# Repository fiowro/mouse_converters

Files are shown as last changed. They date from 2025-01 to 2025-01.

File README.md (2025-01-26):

# mouse_converters

This repo keeps sources (Arduino sketches, STL files for 3D printed parts, pinouts, etc.) for USB mouse converters we created to try out various mice and trackballs while studying the history of cursor control devices. 
Results of the research have their own repo, [github.com/fiowro/mouses](https://github.com/fiowro/mouses) and a dedicated website, [mouses.info](https://mouses.info).

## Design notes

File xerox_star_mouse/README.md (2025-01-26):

# USB Xerox Star mouse converter

This prject allows you to plug Xerox Star two- and three-button mice into USB and use them with any modern computer.

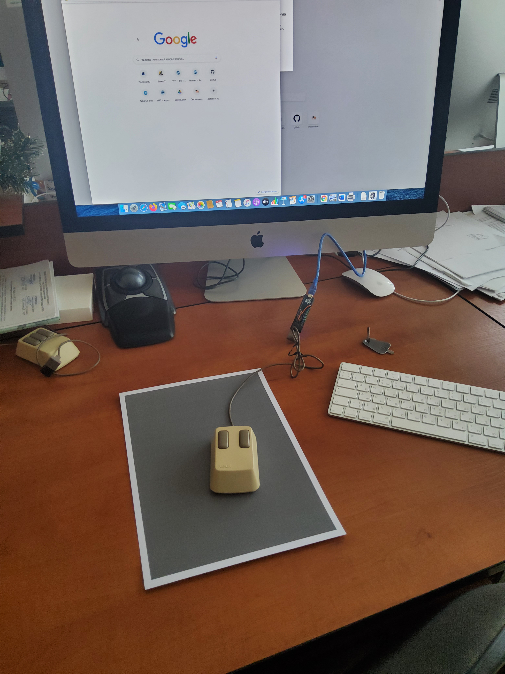
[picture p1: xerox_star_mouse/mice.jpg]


The converter is based on Arduino Pro Micro and uses a sophisticated 3D printed case.

## Mouse jack

Except early versions, these mice have a really esoteric jack:

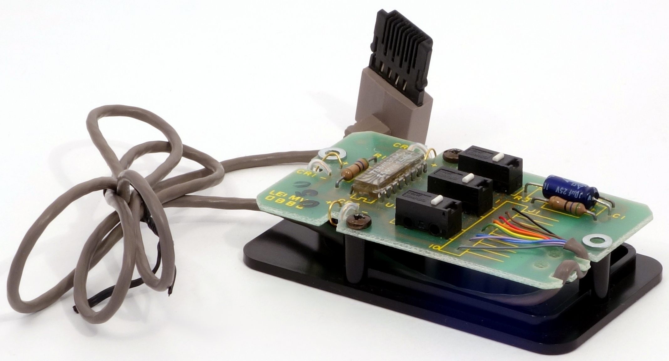
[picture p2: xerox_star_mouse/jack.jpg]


The socket was mounted in the Xerox keyboard and looks like this:

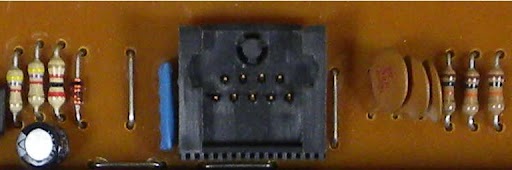
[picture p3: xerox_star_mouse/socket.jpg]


We couldn't find any spare parts, and had to 3D print it as a part of the converter case.
 
The case consists of two parts, one inserted into another (as a drawer).

## Pinout

Xerox Mice are plain quadrature (parallel) cursor movers. It means that coordinates are encoded as Xa, Xb, Ya, Yb, also there are 2 or 3 lines for buttons, power, and ground.
Mouse uses colored wires. 

The pinout of the mouse was figured out experimentally tracking the wires and printed board.

|No.| color | No. | Connected to | Meaning |
|---|---|-----|---|---|
| 1 | red |  3  | U1 ( 7 / 10) | YB |
| 2 | brown |  2  | U1 ( 8 /  9) | YA |
| 3 | yellow|  5  | U1 ( 5 / 12) | XB |
| 4 | orange|  4  | U1 ( 6 / 11) | XA |
| 5 | gray  | 10  | +5V U1 ( 1 / 16) |VDD (+5V)|
| 6 | violet|  8  | GND U1 ( 9 /  8) | GND |
| 7 | black |  1  | S1, U1 (12 /  5) | BD A |
| 8 | blue  |  7  | S2, U1 (15 /  2) | RD B |
| 9 | green |  6  | S3, U1 (14 /  3) | YD A |
| | NC |  9  | GND | |

## Assembly

3D Print the case:

* [ArdMouse4-Body.stl](ArdMouse4-Body.stl) (main part)
* [ArdMouse4-Body001.stl](ArdMouse4-Body001.stl) (cover)

You will need inserting pins into the holes of the *main part* to "assembly" jack.
For example, you can cut off pins from Arduino and use them.

See the [sketch](XeroxDuino.ino) for Arduino pins where to connect the wires (or use your own variant and modify the sketch).

BTW, the sketch is heavily based on the [AmigaInputToUSB](https://github.com/BleuLlama/AmigaInputToUSB) project. 

## Usage

We [recreated the mouse pad](Xerox_mousepad_A4.png) from scratch. You can print it on paper (Xerox did the same) and use.

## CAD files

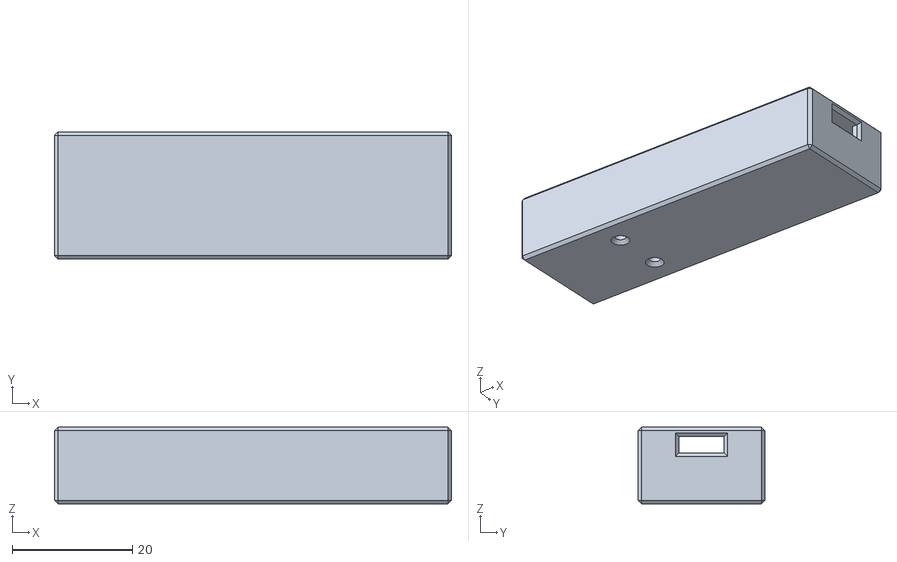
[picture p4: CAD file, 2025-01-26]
xerox_star_mouse/ArdMouse4-Body001.stl
66.1 x 21.2 x 12.8

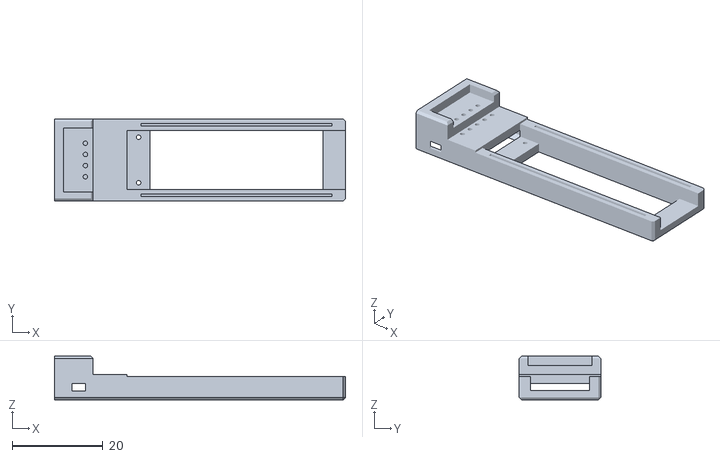
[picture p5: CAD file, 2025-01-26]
xerox_star_mouse/ArdMouse4-Body.stl
64.0 x 18.0 x 9.60

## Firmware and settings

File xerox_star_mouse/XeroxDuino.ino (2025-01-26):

#include <Mouse.h>

// Mouse
#define mousePinYa SCK
#define mousePinXa 7
#define mousePinYb MISO
#define mousePinXb MOSI

// Mouse buttons (common for both)
#define buttonPinL (5)  /* left button (A1) */
#define buttonPinR (6)  /* right button (A3) */
#define buttonPinM (4)  /* middle button (A2) */

// on-board LED pin
// #define kLED (17)

// ----------------------------------------

// setup - initialize the hardware
void setup() {
  pinMode( LED_BUILTIN, OUTPUT );
  
  // set the mouse and button inputs
  pinMode( mousePinYa, INPUT );
  pinMode( mousePinXa, INPUT );
  pinMode( mousePinYb, INPUT );
  pinMode( mousePinXb, INPUT );
  pinMode( buttonPinM, INPUT );
  pinMode( buttonPinL, INPUT );
  pinMode( buttonPinR, INPUT );
  
 // Serial.begin( 9600 );
  Mouse.begin(); // for USB HID Mouse support
  initGrayMouse(); 

}

// mouse movement history, used for acceleration
char history_x[128];
char history_y[128];
int historyPos=0; // current write position in the history

// initialize for gray code mouse 
void initGrayMouse( void )
{
  // clear the history
  for( int h=0 ; h<128 ; h++ ) {
    history_x[h] = history_y[h] = 0;
  }
}

// provide a total of all X history values (for acceleration)
int total_x( void )
{
  int ret = 0;
  for( int i=0 ; i < 128 ; i++ )
  {
    ret += history_x[i];
  }
  return ret;
}

// provide a total of all Y history values (for acceleration)
int total_y( void )
{
  int ret = 0;
  for( int i=0 ; i < 128 ; i++ )
  {
    ret += history_y[i];
  }
  return ret;
}


// compare A and B to determine the delta
  // +  00 -> 01 -> 11 -> 10 -> 00 
  // -  00 -> 10 -> 11 -> 01 -> 00
int grayCompare( int a, int b )
{
  a = a & 0x03;
  b = b & 0x03;
  if( a == b ) return 0;
  switch( a ) {
    case( 0x00 ):
      if( b == 0x01) return +1;
      if( b == 0x10) return -1;
      break;
    case( 0x01 ):
      if( b == 0x11) return +1;
      if( b == 0x00) return -1;
      break;
    case( 0x11 ):
      if( b == 0x10) return +1;
      if( b == 0x01) return -1;
      break;
    case( 0x10 ):
      if( b == 0x00) return +1;
      if( b == 0x11) return -1;
      break;
  }
  return 0;
}

// the main gray mouse loop
void loopGrayMouse()
{
  bool changed = false; // did something change?
  
  // these are static so they persist between calls
  static int x_accum = 0; // accumulated X
  static int y_accum = 0; // accumulated Y

  static int last_hq = 0; // last h quadrature
  static int last_vq = 0; // last v quadrature
  
  // read in the quad/gray code
  int hq = 0;
  int vq = 0;
  
  hq = (digitalRead( mousePinXa ) << 1) | digitalRead( mousePinXb );
  vq = (digitalRead( mousePinYa ) << 1) | digitalRead( mousePinYb );
    
  // check horizontal delta
  if( hq != last_hq ) {
    x_accum += grayCompare( hq, last_hq );
    changed = true;
  }
  last_hq = hq;
  
  // and vertical delta
  if( vq != last_vq ) {
    y_accum += grayCompare( vq, last_vq );
    changed = true;
  }
  last_vq = vq;
    
  // generate the acceleration info from gray tick
  historyPos++;
  history_x[ (historyPos & 0x7f) ] = x_accum;
  history_y[ (historyPos & 0x7f) ] = y_accum;
  int tx = total_x() * 2;
  int ty = total_y() * 2;
  
  // if something changed, move the mouse
  if( x_accum || y_accum ) {
    Mouse.move( tx, ty, 0 );
    x_accum = y_accum = 0;
  }
  
}
 
//////////////////////////////////////////////////////
// handler to read the mouse buttons.
// broke this out since it's the same for mouse vs joystick
void handleButtonPresses()
{
  // b1 = left
  // b2 = right
  // b3 = middle
  
  // left
  static int lb1 = LOW;
  int b1 = digitalRead( buttonPinL );
  
  if( b1 != lb1 ) {
    if( b1 == LOW ) {
      Mouse.press( MOUSE_LEFT );
      delay( 50 ); // fakeo debounce
    }
    if( b1 == HIGH ) Mouse.release( MOUSE_LEFT );
  }
  
  // necessary to prevent mouse fighting
  //if( b1 == HIGH && Mouse.isPressed( MOUSE_LEFT )) {
  //  Mouse.release( MOUSE_LEFT );
  //}
  
  lb1 = b1;

  
  // right
  static int lb2 = LOW;
  int b2 = digitalRead( buttonPinR );
  
  if( b2 != lb2 ) {
    if( b2 == LOW ) {
      Mouse.press( MOUSE_RIGHT );
      delay( 50 ); // fakeo debounce
    }
    if( b2 == HIGH ) Mouse.release( MOUSE_RIGHT );
  }
  // necessary to prevent mouse fighting
  //if( b2 == HIGH && Mouse.isPressed( MOUSE_RIGHT )) {
  //  Mouse.release( MOUSE_RIGHT );
  //}
  lb2 = b2;
  
  
  // middle
  static int lb3 = LOW;
  int b3 = digitalRead( buttonPinM );
  
  if( b3 != lb3 ) {
    if( b3 == LOW ) {
      Mouse.press( MOUSE_MIDDLE );
      delay( 50 ); // fakeo debounce
    }
    if( b3 == HIGH ) Mouse.release( MOUSE_MIDDLE );
  }
  // necessary to prevent mouse fighting
  //if( b3 == HIGH && Mouse.isPressed( MOUSE_MIDDLE )) {
  //  Mouse.release( MOUSE_MIDDLE );
  //}
  lb3 = b3;
}

//////////////////////////////////////////////////////
// main loop
void loop() {
      loopGrayMouse();
      handleButtonPresses();
}
